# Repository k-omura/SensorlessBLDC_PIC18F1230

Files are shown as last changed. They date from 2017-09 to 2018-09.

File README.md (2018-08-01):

# Sensorless BLDC Driver
Sensorless brushless motor controller using PIC18F1230 (XC8)  
* Use only PIC and FET  
* PWM  
* ADC  

-------------------------------------------
# Features(Implemented)  
* Open-loop drive.  
* Closed-loop drive(seamless transfer from open-loop).  
* Closed-loop lock detection(back to open-loop).  
* Speed control by EUSART input.  

-------------------------------------------
# Variables(Implemented)  
* Direction of rotation  
* Open-loop duty  
* Open-loop initial speed  
* Open-loop acceleration  
* Open-loop to closed-loop speed  
* Closed-loop speed  
* Closed-loop acceleration  

-------------------------------------------
# My parts list  
PIC: PIC18F1230 http://ww1.microchip.com/downloads/en/DeviceDoc/39758D.pdf  
NPN Tr: 2SC1815  
MOSFET: SLA5064 http://www.semicon.sanken-ele.co.jp/sk_content/sla5064_ds_en.pdf  
Motor : A2212 13T 950kV/1000kV/1300kV/2300kV, Tarot 4006 620kV  

-------------------------------------------
# Videos  
Closed-loop test: https://youtu.be/z_nNao-uBho  
Lock detection test: https://youtu.be/O4YZ754I2WM  
EUSART speed input with foot pedal: https://youtu.be/TU5dIhgWp5A  

-------------------------------------------
# How to use  
1. install MPLAB X / XC8  
2. create PIC18F1230 project  
3. create main.c in "Source Files"  
4. copy one of the main(---).c  
5. Write it  

-------------------------------------------
This is a part of the quadcopter making project.

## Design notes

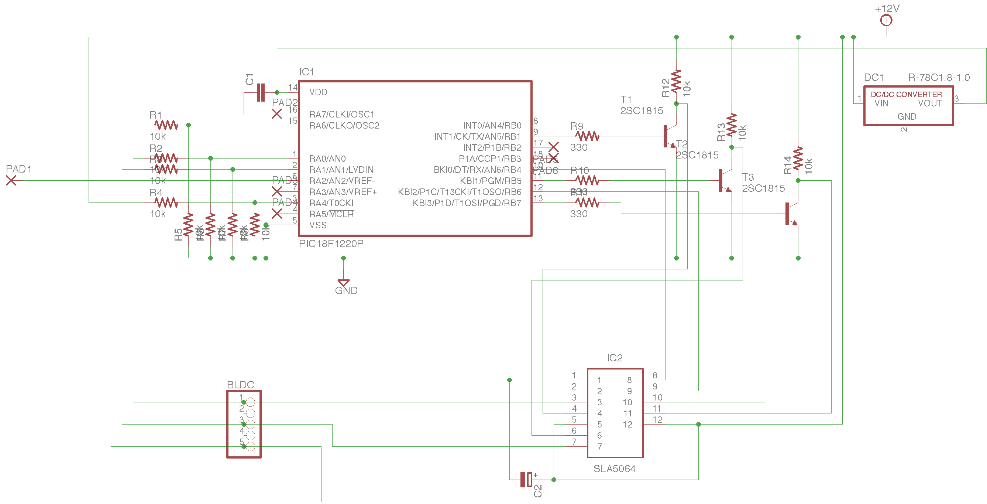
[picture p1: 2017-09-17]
cirquit/BLDC Driver.png

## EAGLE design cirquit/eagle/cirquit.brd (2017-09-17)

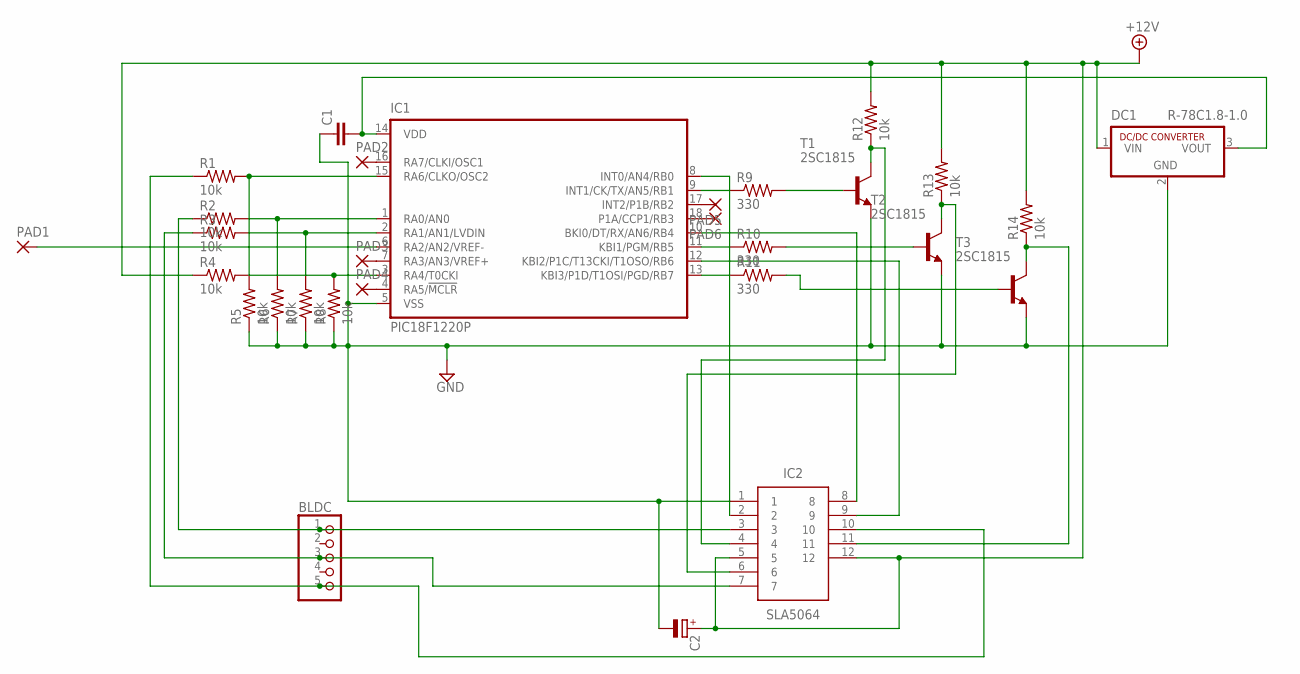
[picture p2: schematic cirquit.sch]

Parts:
BLDC: PINHD-1X5; 1X05
C1: C2.5/2; C2.5-2
C2: CPOL-EUE2,5-6E; E2,5-6E
DC1: R-78C1.8-1.0; SIP3
IC1: PIC18F1220P; DIL18
IC2: SLA5064; TO254P500X3150X1890-12P
PAD1, PAD2, PAD3, PAD4, PAD5, PAD6: 1,6/0,8
R1, R2, R3, R4, R5, R6, R7, R8, R12, R13, R14: 10k; 0204/7
R9, R10, R11: 330; 0204/7
T1, T2, T3: 2SC1815; TO92-ECB

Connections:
+12V: C2.+, DC1.1 (VIN), IC2.5, IC2.12, R4.1, R12.2, R13.2, R14.2
GND: C1.1, C2.-, DC1.2 (GND), IC1.5 (VSS), IC2.1, R5.1, R6.1, R7.1, R8.1, T1.E, T2.E, T3.E
unnamed: IC1.15 (RA6/CLKO/OSC2), R1.2, R5.2
unnamed: IC1.1 (RA0/AN0), R2.2, R6.2
unnamed: IC1.2 (RA1/AN1/LVDIN), R3.2, R7.2
unnamed: IC1.3 (RA4/T0CKI), R4.2, R8.2
unnamed: IC1.16 (RA7/CLKI/OSC1), PAD2.1
unnamed: BLDC.1, IC2.3, R2.1
unnamed: BLDC.3, IC2.7, R3.1
unnamed: IC1.9 (INT1/CK/TX/AN5/RB1), R9.1
unnamed: IC1.11 (KBI1/PGM/RB5), R10.1
unnamed: IC1.13 (KBI3/P1D/T1OSI/PGD/RB7), R11.1
unnamed: R9.2, T1.B
unnamed: R10.2, T2.B
unnamed: R11.2, T3.B
unnamed: IC2.4, R12.1, T1.C
unnamed: IC2.6, R13.1, T2.C
unnamed: IC2.11, R14.1, T3.C
unnamed: IC1.7 (RA3/AN3/VREF+), PAD3.1
unnamed: IC1.4 (RA5/!MCLR), PAD4.1
unnamed: IC1.17 (INT2/P1B/RB2), PAD5.1
unnamed: IC1.18 (P1A/CCP1/RB3), PAD6.1
unnamed: IC1.8 (INT0/AN4/RB0), IC2.2
unnamed: IC1.10 (BKI0/DT/RX/AN6/RB4), IC2.8
unnamed: IC1.12 (KBI2/P1C/T13CKI/T1OSO/RB6), IC2.9
unnamed: IC1.6 (RA2/AN2/VREF-), PAD1.1
unnamed: C1.2, DC1.3 (VOUT), IC1.14 (VDD)
unnamed: BLDC.5, IC2.10, R1.1

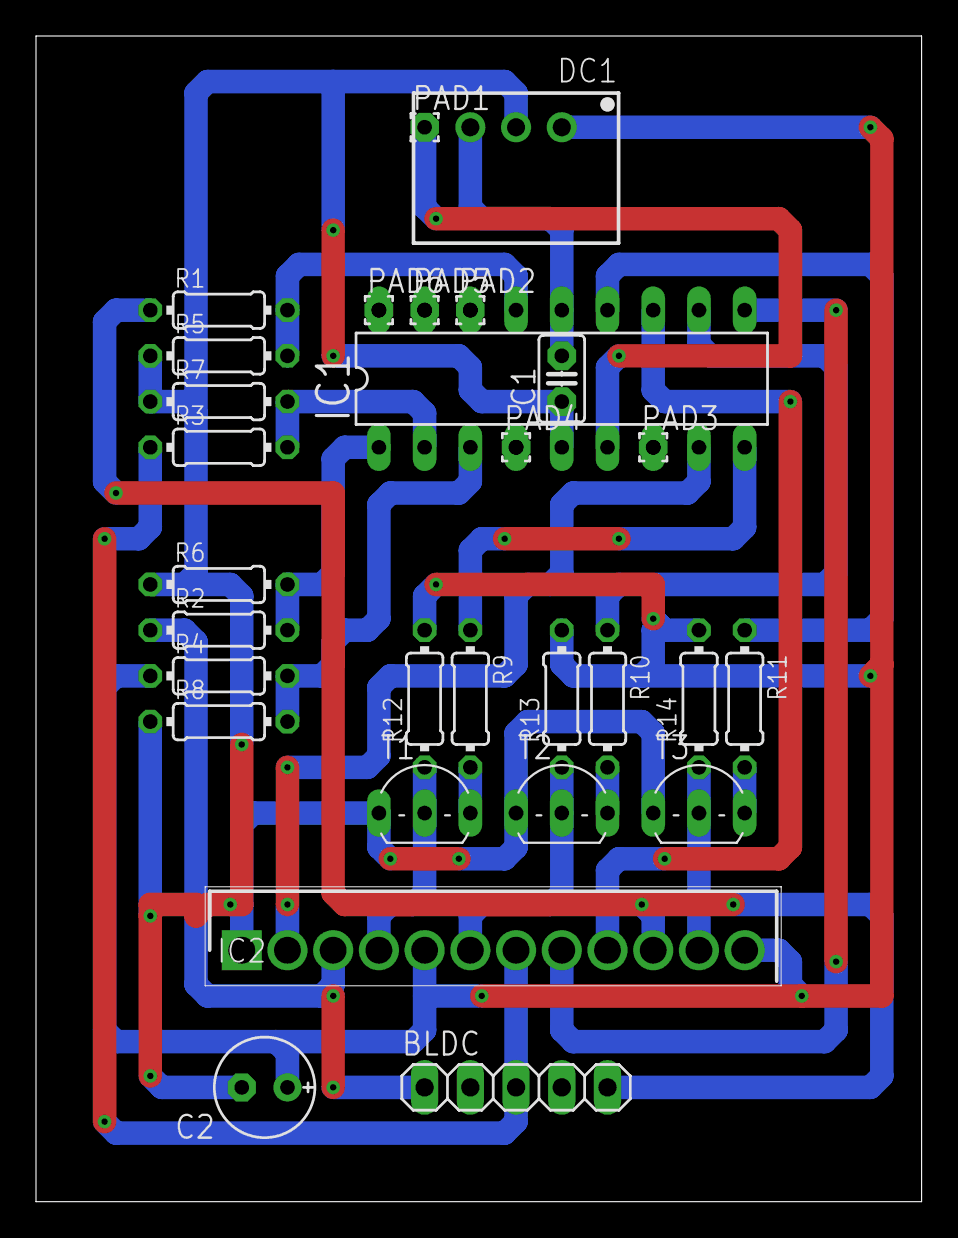
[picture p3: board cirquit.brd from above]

Board: 2 copper layers, 49.2 x 64.8 mm, 29 parts (0 on the bottom side), 28 nets.

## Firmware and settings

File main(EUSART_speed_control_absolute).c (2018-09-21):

/*
 * Created on August 28, 2017
 * August 30, 2017: ADC/PWM test
 * September 10, 2017: Open-loop
 * September 12, 2017: Closed-loop
 * September 13, 2017: Seamless transition Open to Closed, lock detection(CL)
 * January 1, 2018: lock detection(OL)
 * August 1, 2018: Stop using unnecessary functions and use arrays
 * 
 * MPLAB X(XC8)
 * 
 * PWM0: U Nch (Low side)
 * PWM1: U Pch (High side)
 * PWM2: V Nch (Low side)
 * PWM3: V Pch (High side)
 * PWM4: W Nch (Low side)
 * PWM5: W Pch (High side)
 * 
 * ADC0: U
 * ADC1: V
 * ADC2: Supply voltage for motor drive (Vref source -> Vref+ pin)
 * ADC3: W
 * 
 * Speed input EUSART
 * Use RX pin only.
 */

// PIC18F1230 Configuration Bit Settings

// 'C' source line config statements

// CONFIG1H
#pragma config OSC = INTIO2     // Oscillator (Internal oscillator, port function on RA6 and RA7)
#pragma config FCMEN = OFF      // Fail-Safe Clock Monitor Enable bit (Fail-Safe Clock Monitor disabled)
#pragma config IESO = OFF       // Internal/External Oscillator Switchover bit (Oscillator Switchover mode disabled)

// CONFIG2L
#pragma config PWRT = OFF       // Power-up Timer Enable bit (PWRT disabled)
#pragma config BOR = OFF        // Brown-out Reset Enable bits (Brown-out Reset disabled in hardware and software)
#pragma config BORV = 3         // Brown-out Reset Voltage bits (Minimum setting)

// CONFIG2H
#pragma config WDT = OFF        // Watchdog Timer Enable bit (WDT disabled (control is placed on the SWDTEN bit))
#pragma config WDTPS = 32768    // Watchdog Timer Postscale Select bits (1:32768)

// CONFIG3L
#pragma config PWMPIN = OFF     // PWM Output Pins Reset State Control bit (PWM outputs disabled upon Reset)
#pragma config LPOL = HIGH      // Low-Side Transistors Polarity bit (Even PWM Output Polarity Control bit) (PWM0, PWM2 and PWM4 are active-high (default))
#pragma config HPOL = HIGH      // High Side Transistors Polarity bit (Odd PWM Output Polarity Control bit) (PWM1, PWM3 and PWM5 are active-high (default))

// CONFIG3H
#pragma config FLTAMX = RA5     // FLTA Mux bit (FLTA input is muxed onto RA5)
#pragma config T1OSCMX = LOW    // T1OSO/T1CKI MUX bit (T1OSO/T1CKI pin resides on RB2)
#pragma config MCLRE = OFF      // Master Clear Enable bit (RA5 input pin enabled, MCLR pin disabled)

// CONFIG4L
#pragma config STVREN = OFF     // Stack Overflow/Underflow Reset Enable bit (Reset on stack overflow/underflow disabled)
#pragma config BBSIZ = BB256    // Boot Block Size Select bits (256 Words (512 Bytes) Boot Block size)
#pragma config XINST = OFF      // Extended Instruction Set Enable bit (Instruction set extension and Indexed Addressing mode disabled)

// CONFIG5L
#pragma config CP0 = OFF        // Code Protection bit Block 0 (000400-0007FF) (Block 0 is not code-protected)
#pragma config CP1 = OFF        // Code Protection bit Block 1 (000800-000FFF) (Block 1 is not code-protected)

// CONFIG5H
#pragma config CPB = OFF        // Code Protection bit (Boot Block Memory Area) (Boot Block is not code-protected)
#pragma config CPD = OFF        // Code Protection bit (Data EEPROM) (Data EEPROM is not code-protected)

// CONFIG6L
#pragma config WRT0 = OFF       // Write Protection bit Block 0 (000400-0007FF) (Block 0 is not write-protected)
#pragma config WRT1 = OFF       // Write Protection bit Block 1 (000800-000FFF) (Block 1 is not write-protected)

// CONFIG6H
#pragma config WRTC = OFF       // Write Protection bit (Configuration Registers) (Configuration registers are not write-protected)
#pragma config WRTB = OFF       // Write Protection bit (Boot Block Memory Area) (Boot Block is not write-protected)
#pragma config WRTD = OFF       // Write Protection bit (Data EEPROM) (Data EEPROM is not write-protected)

// CONFIG7L
#pragma config EBTR0 = OFF      // Table Read Protection bit Block 0 (000400-0007FF) (Block 0 is not protected from table reads executed in other blocks)
#pragma config EBTR1 = OFF      // Table Read Protection bit Block 1 (000800-000FFF) (Block 1 is not protected from table reads executed in other blocks)

// CONFIG7H
#pragma config EBTRB = OFF      // Table Read Protection bit (Boot Block Memory Area) (Boot Block is not protected from table reads executed in other blocks)

// #pragma config statements should precede project file includes.
// Use project enums instead of #define for ON and OFF.

#include <xc.h>

#define _XTAL_FREQ 32000000
#define motorADCThreshold 0x80 // (Vmotor / 2) Adjust the value by looking at the oscilloscope, if necessary.
#define CLLockDetectionThreshold 1000
#define OLLockDetectionThreshold 500

//configurations (Set for A2212 13T 1000KV)
#define configDirection 0//rotate direction 0:CW /1:CCW /others:stop
#define configOLDuty 0x60//Open-loop duty (higher is faster)
#define configOLInitialSpeed 200 //Open-loop initial speed (lower is faster)
#define configOpenToCloseSpeed 100 //Open to close speed (Open-loop max speed) (lower is faster)
#define configOLaccelerate 10 //Open-loop "OLInitialSpeed" to "openToCloseSpeed" acceleration (higher is faster)
#define configCLaccelerate 20000 //Closed-loop acceleration (lower is faster)
//configurations end

//functions
int math_abs(int);
void setDuty(unsigned char);
char chageDutySmoothly(unsigned char, unsigned int);
void nextState(unsigned char);

//var
unsigned char motorPosition;
unsigned char direction; //rotation direction. 0, 1, others
unsigned char CLEnable = 0;
unsigned char reachO2CSpeed = 0;
unsigned char LockDetected = 0;

unsigned char eusartReceiveDataGet = 0; //flag read value
unsigned char eusartReceiveData = 0;

//const
const unsigned char ADCPortCHS[3] = {0b00, 0b01, 0b11};
const unsigned char feedBackConstant[2][6] = {
    {
        0b00000110,
        0b00000100,
        0b00000101,
        0b00000001,
        0b00000011,
        0b00000010
    },
    {
        0b00000010,
        0b00000110,
        0b00000100,
        0b00000101,
        0b00000001,
        0b00000011
    }
};
//PWM on/off config
const unsigned char PWMpins[] = {
    0b00001001,
    0b00100001,
    0b00100100,
    0b00000110,
    0b00010010,
    0b00011000,
    0b00000000
};

void __interrupt() isr() {
    static unsigned char ADCPortNum = 0; //counter for ADCPortCHS
    static unsigned char ADCValue[3] = {0};
    static unsigned int CLLockDetectionCount = 0;
    static unsigned int OLLockDetectionCount = 0;

    unsigned char BEMFValue;

    if (PIR1bits.ADIF) {
        ADCValue[ADCPortNum] = ADRESH;

        ADCPortNum = (ADCPortNum >= 2) ? 0 : (ADCPortNum + 1);

        if (ADCPortNum == 0) { //AD Convert all of UVW
            //BEMF
            BEMFValue = 0b00000000;
            BEMFValue += (ADCValue[0] > motorADCThreshold) ? 0b00000001 : 0;
            BEMFValue += (ADCValue[1] > motorADCThreshold) ? 0b00000010 : 0;
            BEMFValue += (ADCValue[2] > motorADCThreshold) ? 0b00000100 : 0;

            if ((feedBackConstant[direction][motorPosition] == BEMFValue) && reachO2CSpeed) {
                //change motor position
                nextState(direction);
                CLLockDetectionCount = 0;
                OLLockDetectionCount = 0;
                CLEnable = 1;
            } else if (!CLEnable && reachO2CSpeed && (OLLockDetectionThreshold < OLLockDetectionCount++)) {
                //lock detected(OL)
                reachO2CSpeed = 0;
                OVDCOND = PWMpins[6];
                setDuty(0x00);
                CLEnable = 0;
                CLLockDetectionCount = 0;
                OLLockDetectionCount = 0;
                LockDetected = 1;
            } else if (CLEnable && (CLLockDetectionThreshold < CLLockDetectionCount++)) {
                //lock detected(CL)
                reachO2CSpeed = 0;
                OVDCOND = PWMpins[6];
                setDuty(0x00);
                CLEnable = 0;
                CLLockDetectionCount = 0;
                OLLockDetectionCount = 0;
                LockDetected = 1;
            }
        }

        ADCON0bits.CHS = ADCPortCHS[ADCPortNum];
        PIR1bits.ADIF = 0;
    }
    if (PIR1bits.RCIF) {
        if (RCSTAbits.OERR || RCSTAbits.FERR) {
            RCSTAbits.CREN = 0;
            eusartReceiveData = RCREG;
            RCSTAbits.CREN = 1;
        } else {
            eusartReceiveData = RCREG;
            eusartReceiveDataGet = 0;
        }
        PIR1bits.RCIF = 0;
    }
    /*
    if (INTCONbits.TMR0IF) {
        INTCONbits.TMR0IF = 0;
    }
    */

    return;
}

void main(void) {
    OSCCON = 0b01110000; //INTOSC 8MHz
    OSCTUNE = 0b01000000; //PLL on

    TRISA = 0b01011011; //AN0-3, RX input
    TRISB = 0b00000000;
    PORTA = 0b00000000;
    PORTB = 0b00000000;

    //interrupt
    INTCON = 0b11000000; //
    INTCON2 = 0b00000000;
    INTCON3 = 0b00000000;

    //configure timer 0
    T0CON = 0b01000000;

    //configure ADC
    ADCON0 = 0b10000000; //Special Event Trigger Enable
    ADCON1 = 0b00010000; //Vref source -> Vref+ pin
    ADCON2 = 0b00001000; //left justified

    //configure PWM
    PTCON0 = 0b00000010; //Postscale 1:1, Fosc/4 Prescale 1:1
    PTCON1 = 0b10000000; //Time base in ON, Time base counts up
    PWMCON0 = 0b01000111; //All PWM I/O pins enabled for PWM output, Independent mode for all pins
    PWMCON1 = 0b00000001; //Postscale 1:1, special event on count downwards, updates from Duty Cycle and Period Buffers enabled
    OVDCOND = 0b00000000;
    OVDCONS = 0b00000000;
    //Period control for all PWM output
    PTPERH = 0x00;
    PTPERL = 0x3f; //8bit PWM
    DTCON = 0b00000110;
    SEVTCMPH = 0;
    SEVTCMPL = 1;
    //FLTCONFIG = 0b00000010;

    PDC0H = 0; //Duty Cycle control for PWM0/1
    PDC0L = 0; //Duty Cycle control for PWM0/1

    PDC1H = 0; //Duty Cycle control for PWM2/3
    PDC1L = 0; //Duty Cycle control for PWM2/3

    PDC2H = 0; //Duty Cycle control for PWM4/5
    PDC2L = 0; //Duty Cycle control for PWM4/5
    chageDutySmoothly(0, 0);

    //configure EUSART receive
    TXSTA = 0b00000100; //BRGH = 1 high speed
    RCSTA = 0b10010000;
    BAUDCON = 0b00001000; //16-bit Baud Rate Generator
    SPBRGH = 0;
    SPBRG = 68; //Baud Rate 115200 (Formula: 115942.029)
    /*
     * SPBRG = 832 : Baud Rate 9600 (Formula: 9603.842)
     * SPBRG = 138 : Baud Rate 57600 (Formula: 57553.957)
     * SPBRG = 68; //Baud Rate 115200 (Formula: 115942.029)
     */

    //start timer 0
    T0CONbits.TMR0ON = 0;
    INTCONbits.TMR0IE = 0;

    //start ADC
    ADCON0bits.CHS = ADCPortCHS[0];
    ADCON0bits.ADON = 1;
    __delay_ms(50);
    ADCON0bits.GO_nDONE = 1;
    PIE1bits.ADIE = 1;

    //start EUSART interrupt
    PIE1bits.RCIE = 1;

    //var for open-loop
    unsigned char OLDuty, OLaccelerate;
    unsigned int OLInitialSpeed, openToCloseSpeed, OLSpeedCount, OLAccelerateCount;

    //var for closed-loop
    unsigned char CLDuty, CLInitialSpeedReached;
    unsigned int CLaccelerate;

    //var others
    unsigned char duty;

    //Initial configuration
    direction = configDirection; //rotate direction 0:CW /1:CCW /others:stop
    OLDuty = configOLDuty; //Open-loop duty
    OLInitialSpeed = configOLInitialSpeed; //Open-loop initial speed
    openToCloseSpeed = configOpenToCloseSpeed; //Open to close speed (Open-loop max speed)
    OLaccelerate = configOLaccelerate; //Open-loop "OLInitialSpeed" to "openToCloseSpeed" acceleration
    CLaccelerate = configCLaccelerate; //Closed-loop acceleration
    //Initial configuration end

    //initialize
    LockDetected = 1; //motor is stopped in the initial state.
    CLDuty = 0;
    CLInitialSpeedReached = 0;
    eusartReceiveData = 0;
    //initialize end

    //main motor control part
    while (1) {
        if (LockDetected) {
            //initialize. first start or lock detected(CL)
            duty = 0x00;
            motorPosition = 0; //Motor initial position
            CLEnable = 0; //Closed-loop enable flag
            OLAccelerateCount = OLInitialSpeed;
            chageDutySmoothly(OLDuty, 0); //initialize static var in function "prevDuty".
            LockDetected = 0;
            CLInitialSpeedReached = 0;
            reachO2CSpeed = 0;
            //initialize end
        }
        
        if (!CLEnable && CLDuty) { //start motor with open-loop
            setDuty(duty);

            duty = (duty < OLDuty) ? duty + 1 : OLDuty;
            OLAccelerateCount = ((OLAccelerateCount - OLaccelerate) > openToCloseSpeed) ? (OLAccelerateCount - OLaccelerate) : openToCloseSpeed;

            //change motor position
            nextState(direction);

            //transition to closed-loop
            if (OLAccelerateCount == openToCloseSpeed) {
                reachO2CSpeed = 1;
            }

            for (OLSpeedCount = 0; OLSpeedCount < OLAccelerateCount; OLSpeedCount++) {
                __delay_us(10);
            }
        } else { //Closed-loop
            chageDutySmoothly(duty, CLaccelerate);
            //CLDuty = 0xff; //test constant speed CL-drive value
            duty = CLDuty;
        }
        
        //Processing EUSART speed input 
        if (!eusartReceiveDataGet) {
            eusartReceiveDataGet = 1;
            if (eusartReceiveData) {
                CLDuty = eusartReceiveData;//Absolute speed control
            } else {
                //EUSART input 0
                reachO2CSpeed = 0;
                OVDCOND = PWMpins[6];
                setDuty(0x00);
                CLEnable = 0;
                CLDuty = 0;
                CLInitialSpeedReached = 0;
                LockDetected = 1;
            }
        }
    }

    return;
}

//math abs

int math_abs(int value) {
    return (value >= 0) ? value : -value;
}

//PWM duty ratio = Current supply to motor = speed of motor(closed-loop))

void setDuty(unsigned char setDuty) {
    PDC0L = setDuty;
    PDC1L = setDuty;
    PDC2L = setDuty;

    return;
}

//change PWM duty ratio smoothly. Output 1 when the target speed is reached.

char chageDutySmoothly(unsigned char targetDuty, unsigned int acceleration) {
    static unsigned char prevDuty = 0;
    unsigned int accelerateCount;

    if (targetDuty == prevDuty) {
        return 1;
    }

    if (acceleration == 0) {
        prevDuty = targetDuty;
        return 1;
    }

    //Preventing step-out by rapid acceleration.
    if (math_abs(targetDuty - prevDuty) > 64) {
        acceleration = 100;
    }

    prevDuty = (targetDuty > prevDuty) ? (prevDuty + 1) : (prevDuty - 1);
    setDuty(prevDuty);
    
    if (targetDuty == prevDuty) {
        return 1;
    }
    
    for (accelerateCount = 0; accelerateCount < acceleration; accelerateCount++) {
        __delay_us(1);
    }

    return 0;
}

//rotate

void nextState(const unsigned char directionSet) {
    if (directionSet == 0) {
        motorPosition = (motorPosition == 5) ? 0 : motorPosition + 1;
    } else if (directionSet == 1) {
        motorPosition = (motorPosition == 0) ? 5 : motorPosition - 1;
    } else {
        //stop
        reachO2CSpeed = 0;
        OVDCOND = PWMpins[6];
        setDuty(0x00);
        CLEnable = 0;
        LockDetected = 1;
    }
    OVDCOND = PWMpins[motorPosition];

    return;
}

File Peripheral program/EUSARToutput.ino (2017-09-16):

/*
 * Arduino program
 * test for main(EUSART_speed_control_absolute).c
 */

int i;
void setup() {
  Serial.begin(115200);
}

void loop() {
  Serial.write(0b00000000);
  delay(2000);

  Serial.write(0b00110000);
  delay(2000);

  Serial.write(0b01110000);
  delay(2000);

  Serial.write(0b11110000);
  delay(2000);

  for (i = 0; i < 20; i++) {
    Serial.write(0b11110000);
    delay(50);
    Serial.write(0b11100000);
    delay(50);
  }
}
